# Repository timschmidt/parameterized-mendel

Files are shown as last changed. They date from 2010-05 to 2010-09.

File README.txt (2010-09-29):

Parameterized Mendel
====================

http://reprap.org/wiki/Parameterized_Mendel

This repository contains CAD files for the RepRap Mendel model 3D printer.

The v1.0 directory is intended to house a version of the Mendel which closely resembles the one initially released at reprap.org. Bugfixes and minor improvements will be incorporated, but always with an eye toward backwards compatibility.

The v1.1 directory is intended to house current development on the Mendel CAD files, including but not limited to porting to the MCAD library, radical improvements, and integration with the Huxley CAD files.

The experimental directory is a place for ideas to be developed, awaiting integration into either v1.0 or v1.1.

The utilities directory houses various programs which developers and end users may find useful when working with the CAD files.

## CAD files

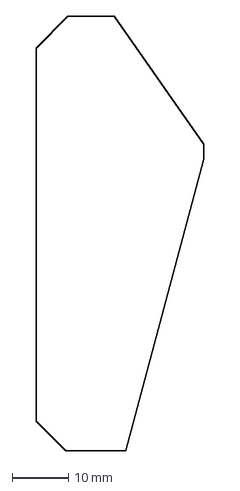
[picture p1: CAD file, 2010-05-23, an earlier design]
v1.0/y-idler-bracket-outline.dxf
29.7 x 76.9 mm

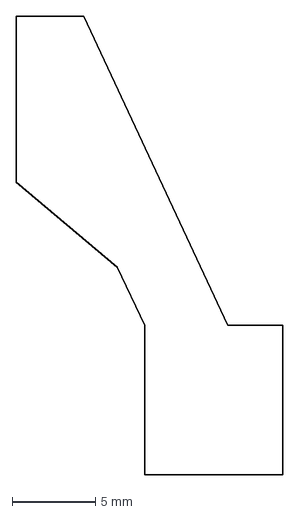
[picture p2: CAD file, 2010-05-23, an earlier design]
v1.0/x-360-z-bearing-plate-bottom-outline.dxf
16.0 x 27.6 mm

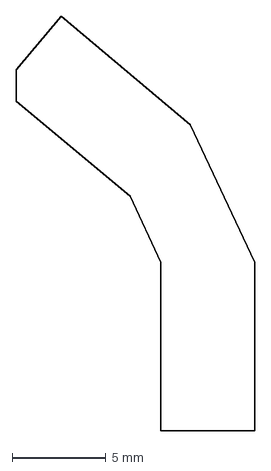
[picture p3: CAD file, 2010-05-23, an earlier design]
v1.0/x-360-z-bearing-plate-top-outline.dxf
12.7 x 22.1 mm

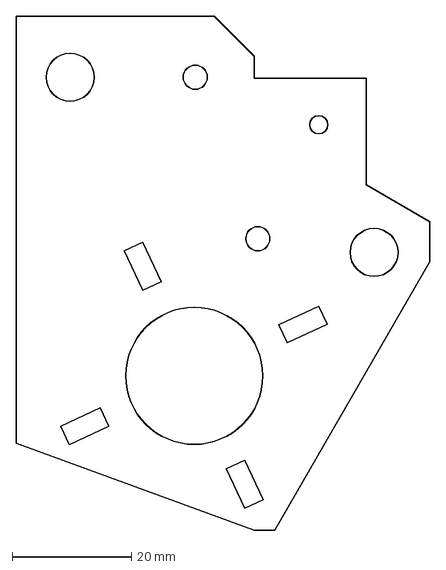
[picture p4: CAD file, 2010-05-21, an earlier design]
v1.0/y-motor-bracket.dxf
69.4 x 86.2 mm

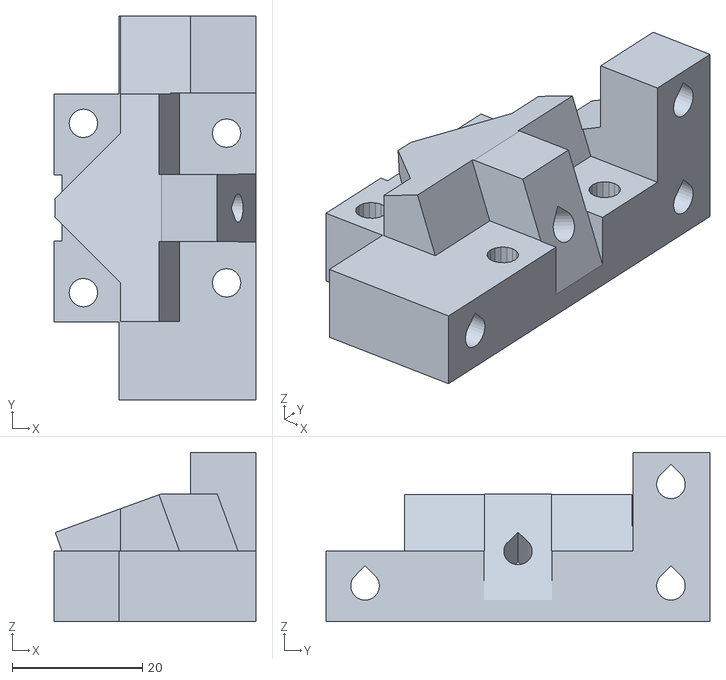
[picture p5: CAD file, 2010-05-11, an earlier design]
v1.0/y-bearing-360-outer-left_1off.stl
31.0 x 59.0 x 26.0

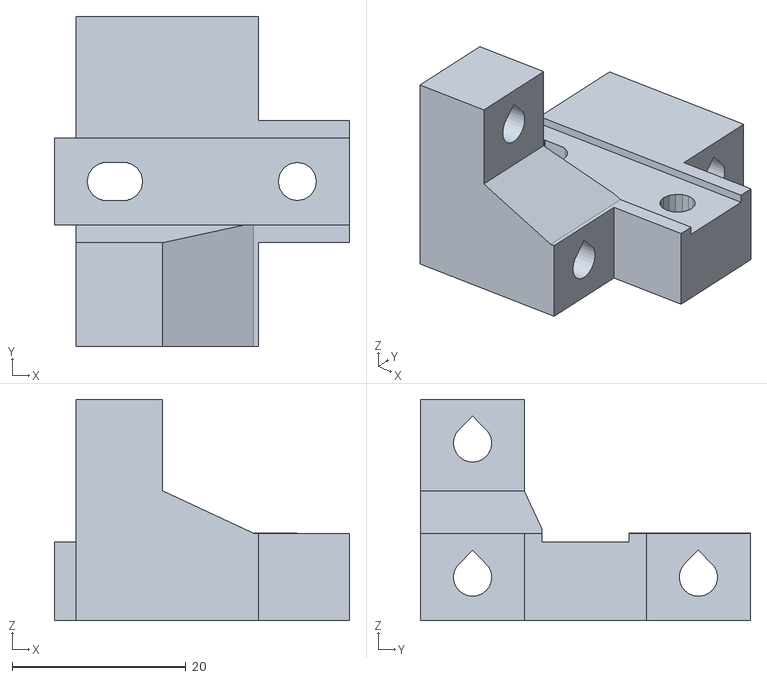
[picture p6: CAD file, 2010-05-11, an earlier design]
v1.0/y-bearing-180-outer-left_1off.stl
34.0 x 38.0 x 25.5

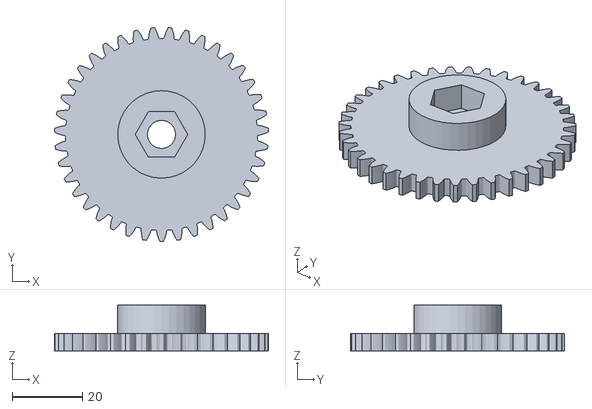
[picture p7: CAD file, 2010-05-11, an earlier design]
v1.0/39t17p.stl
61.1 x 61.1 x 13.0

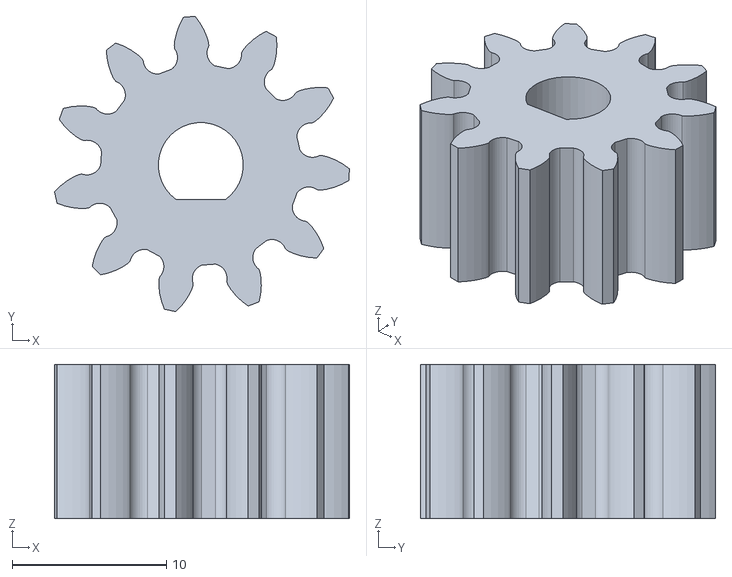
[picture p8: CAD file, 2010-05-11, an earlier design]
v1.0/11t17p.stl
19.1 x 19.1 x 10.0

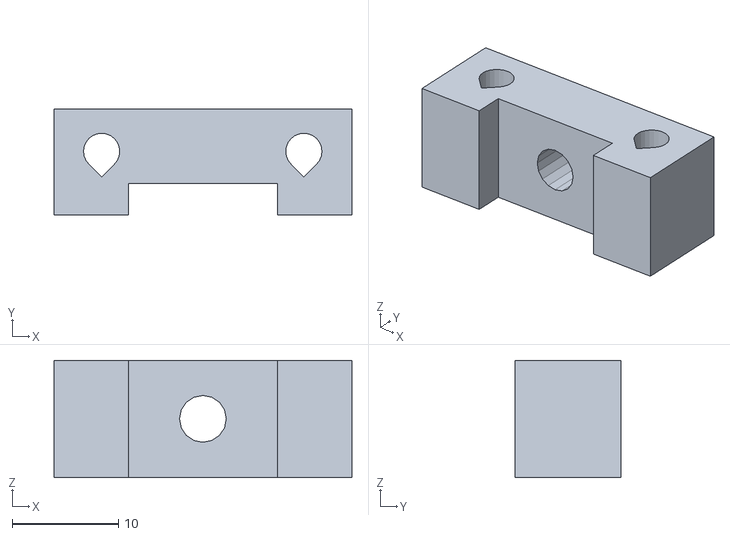
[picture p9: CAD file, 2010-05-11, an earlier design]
v1.0/z-opto-bracket_1off.stl
28.0 x 9.99 x 11.0

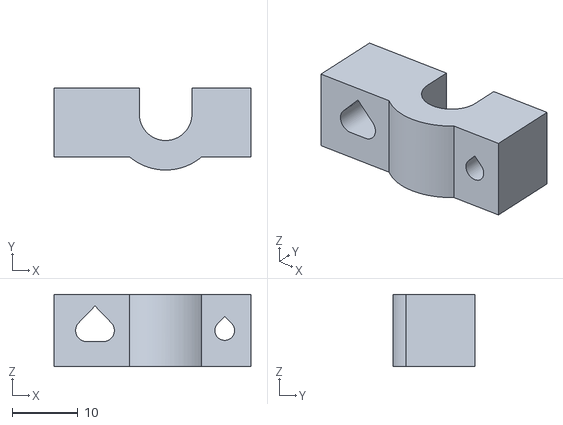
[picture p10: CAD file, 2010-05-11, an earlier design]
v1.0/x-bar-clamp-m3_6off.stl
30.0 x 12.5 x 11.0

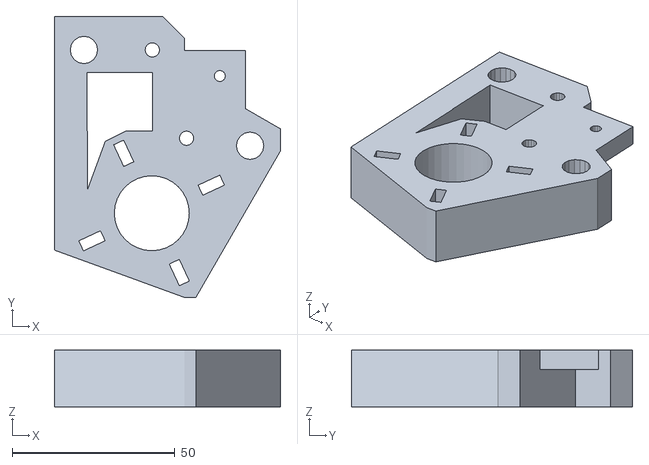
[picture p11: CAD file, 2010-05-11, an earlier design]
v1.0/y-motor-bracket_1off.stl
69.4 x 86.2 x 17.5

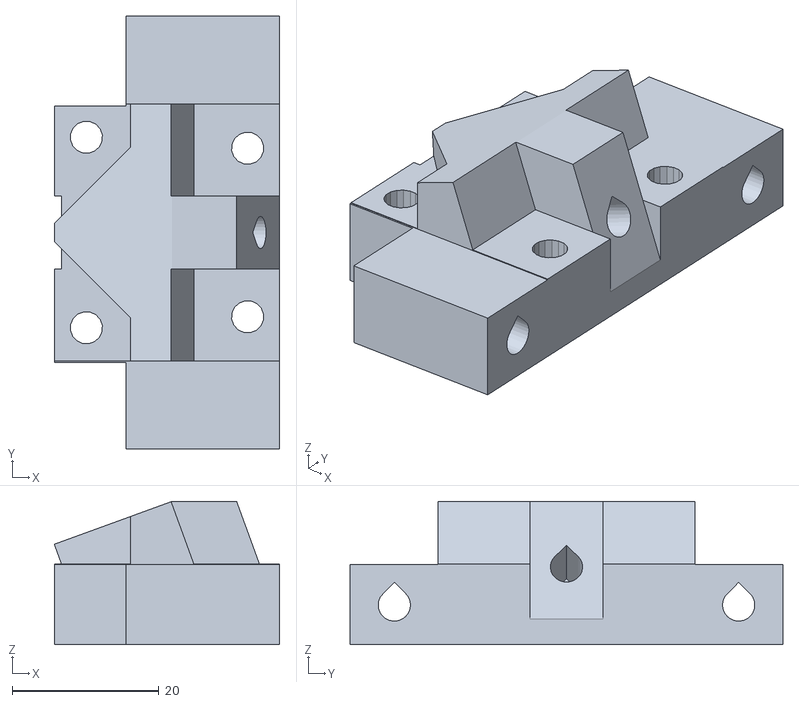
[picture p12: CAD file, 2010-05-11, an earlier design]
v1.0/y-bearing-360-inner_2off.stl
30.7 x 59.1 x 19.5

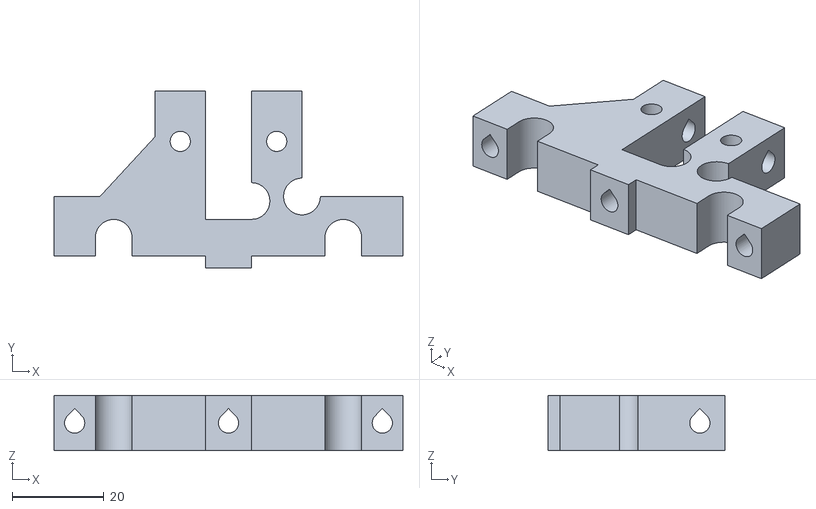
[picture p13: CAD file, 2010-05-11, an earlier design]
v1.0/x-180-z-bearing-plate_2off.stl
76.0 x 38.6 x 12.0

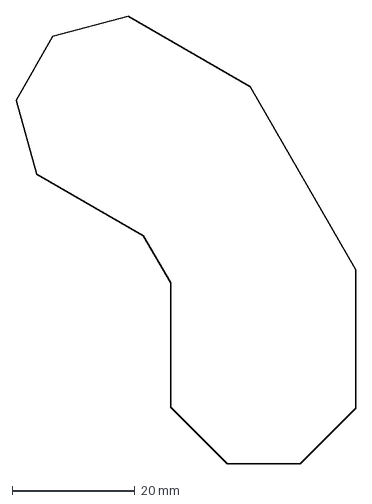
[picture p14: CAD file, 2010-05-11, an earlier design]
v1.0/frame-vertex.dxf
55.4 x 72.9 mm

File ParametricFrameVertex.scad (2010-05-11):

// Parametric Frame Vertex by Tonokip
// 2009.02.08
// Vertex Body derived from: frame-vertex_6off.aoi::body - edges
// http://reprap.svn.sourceforge.net/viewvc/reprap/trunk/mendel/mechanics/solid-models/cartesian-robot-m4/printed-parts/
// Fixed body geometry flaw per http://dev.forums.reprap.org/read.php?1,30132,30398
// License GNU GPL v2 or newer.

M3=4.3; 
M8=9.6;
vertex_height=20;
with_foot=1;		// Comment out for no foot.

FN=80;

translate ([0,0,vertex_height/2])difference() 
{
	union () {
		dxf_linear_extrude(file = "vertex-body-fixed-qcad.dxf",height=vertex_height,center=true);
		//import_stl("vertex-body-fixed.stl");
		if (with_foot==1) {
			translate([40,-15,0]) vertex_foot();
		}
	}

	translate([11.013,59.912]) zhole(M8); 
	translate([35.013,39.999,0]) zhole(M8); 
	translate([40.274,9.249,0]) zhole(M8); 
	translate([40.217,30.992]) zhole(M3); 
	translate([29.829,48.986]) zhole(M3); 
	translate([0,21,0]) 
		xteardrop(M8,200);
	translate([13.687,41.010,0]) rotate(a=60,v=[0,0,1])
		xteardrop(M8,200);
}


module zhole(diameter) cylinder(h=100,r=(diameter/2),center=true,$fn=FN); 

module xteardrop(diameter,length) rotate(a=-90,v=[0,1,0]) rotate(a=-90,v=[0,0,1]) zteardrop(diameter,length);

module yteardrop(diameter,length) rotate(a=90,v=[1,0,0]) zteardrop(diameter,length);

module zteardrop(diameter,height)
{
	rotate(a=45, v=[0,0,1]) union()
	{
		translate([0,0,-height/2]) cube(size=[diameter/2,diameter/2,height],center=false);
		cylinder(r=diameter/2, h = height,center=true,$fn=FN);
	}
}

module vertex_foot() {
	difference () {
		union () {
			cube([18,4,vertex_height],center=true);
			translate ([-5,8,0]) cube([5,18,vertex_height],center=true);
			translate ([5,9,0]) cube([5,18,vertex_height],center=true);
		}
		translate ([0,8,0]) xteardrop(7,200);
	}
}

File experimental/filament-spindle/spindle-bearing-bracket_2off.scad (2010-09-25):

/*
 *  Mendel Filament Spindle Bearing Bracket 2off
 *  by Tony Buser <tbuser@gmail.com>
 *
 *  This program is free software; you can redistribute it and/or modify
 *  it under the terms of the GNU General Public License as published by
 *  the Free Software Foundation; either version 3 of the License, or
 *  (at your option) any later version.
 *
 *  This program is distributed in the hope that it will be useful,
 *  but WITHOUT ANY WARRANTY; without even the implied warranty of
 *  MERCHANTABILITY or FITNESS FOR A PARTICULAR PURPOSE.  See the
 *  GNU General Public License for more details.
 *
 *  You should have received a copy of the GNU General Public License
 *  along with this program; if not, write to the Free Software
 *  Foundation, Inc., 59 Temple Place, Suite 330, Boston, MA  02111-1307  USA
*/

include <../mendel.inc>
include <../mendel.conf>

include <spindle.scad>

bearing_bracket_width = 22;
bearing_bracket_length = 21;
bearing_bracket_height = 33;

module bearing_bracket() {
	difference () {

		// TODO: chamfer?
		box(bearing_bracket_width, bearing_bracket_length, bearing_bracket_height);

		// shaft
		translate([0, bearing_bracket_length/2-rod_diameter+1, bearing_bracket_height/2-rod_diameter+1]) {
			rotate([-90, 0, -90]) {
				spindle_hole_horiz(bearing_bracket_width+2);
			}
		}

		// front nut
		translate([0, -bearing_bracket_length/2+3-1, bearing_bracket_height/2-rod_diameter+1]) {
			// top side cutout
			translate([0, 0, rod_diameter/2]) box(rod_diameter, rod_diameter-1, rod_diameter);

			rotate([0, -90, 90]) {
				spindle_hole_vert(rod_diameter+2);
			}
			rotate([90, 0, 0]) {
				spindle_nut_cavity(rod_diameter-1);
			}
		}

	}
}

translate([0, 0, bearing_bracket_length/2]) {
	rotate([-90]) bearing_bracket();
}

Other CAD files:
v1.0/y-bearing-180-outer-right_1off.stl
v1.0/y-bearing-180-inner_2off.stl
v1.0/y-bearing-360-outer-right_1off.stl
v1.0/x-axis-side-plate-nut-jig_2off.stl
experimental/filament-spindle/spindle-corner-bracket_8off.scad
experimental/filament-spindle/spindle-hub_1off.scad
experimental/bfb-and-dualhead/mendel_x_carriage_lower_bfb.scad
experimental/bfb-and-dualhead/mendel_x_carriage_lower_bfb_2head.scad
experimental/bfb-and-dualhead/mendel_x_carriage_upper_bfb_2head.scad
experimental/filament-spindle/spindle-spool-hub_1off.scad
experimental/filament-spindle/spindle-spool-spoke_4off.scad
experimental/filament-spindle/spindle-support-bearing-bracket_4off.scad
experimental/filament-spindle/spindle-tube-fitting.scad
experimental/filament-spindle/spindle-tube-holder_1off.scad
experimental/filament-spindle/spindle.scad
experimental/gears_spur.scad
experimental/huxley/Huxley.scad
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

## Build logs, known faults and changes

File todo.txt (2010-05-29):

Todo:

-- Short Term Goals --
 - replace all STLs with OpenSCAD files

-- Medium Term Goals --
 - improve parameterization
  - move all defined constants into mendel.conf
  - consolidate modules in mendel.inc
  - re-use constants and modules wherever possible
  - create commented pre-defined configurations of the mendel in mendel.conf for easy selection of a few major variants

-- Long Term Goals --
 - improve servicability
  - re-design parts to allow any individual part to be removed without requiring significant disassembly
  - modify parts for easy tool access after installation

-- Individual Items --
 - fix vik's fudging of various hole diameters
 - unify z leadscrew base, z motor bracket, and z tensioner bracket files - optionally render as individual or combined parts
 - parameterize foot height on frame vertex, and make middle three holes optional
 - merge x carriage upper and lower with modified bfb versions
 - thin the X vert drive side plate 180 a bit, to reduce X axis guide rod bending
 - add nut trap void to x vert side plate 180, eliminate nut trap jig part.
 - de-couple the Z drive trapped nut a bit, to dampen drive rod wobble

-- Additions from fen for mini-mendel --
z axis rod clamp is not the same spacing as other 6mm clamp arch thingies
clamp arch thingies should accept 20mm m3 shcs
clamp arch thingies are too small for 6mm rods
clamp arch thingies should work with 20mm m3's, and have hexagon nut holders
90 degree thingies should only need 1 clamp screw each
y front clamp thingy screws interfere with nema 17 motor
enlarge 22mm holes in motor connector interfaces to accomodate larger pulley hubs + set screws sticking out

reduce number of 30mm m3's to <50 qty
eliminate 12mm m3's
z axis 180 should be 1 piece.. shouldnt need washers to offset the bearings
move z 180 side leadscrew closer to smooth z rod, to increase x travel
space for washer on z 360 piece. reengineer z 360 assy to not need threaded rod
add holes for nema17 on x y z
z nut traps only need 4 screws, two on the outside, and front and back of the screw
get rid of nut traps on y chassis
fix misaligned counterbore on x carriage
get rid of counterbores on x carriage, switch to hexagons
x-carriage hexagon should be symmetrical (two less holes? what are they for?)
x carriage triangular lumps may interfere with bearing next to it
x carriage triangular lumps need nut bearing surface on opposite side
x carriage needs a little more stiffness (thickness at thinnest part)
x carriage diagonal 30mm m3's interfere with vertical 20mm's (barely)
x carriage should be symmetrical distance from rods or belt will rub on backside
x carriage only needs one vertical 360 bearing and should have outer diagonals on ends (wider wheelbase = more rigidity against racking forces)
speaking of racking forces, belt clamp should be more central (offset motor, huge redesign of x axis)
belt clamp should have same spacing as arch thingies
y 360 sliders are too wide for 30mm m3+two nuts + lock washer (barely) (+two washers would be nice)
only need 2 y 180's, not 4
true kinematic design would use less bearings
lower y axis somehow, it's too much clearance between bottom of y and bottom of machine, i.e. switch z tension rods+frame rods
purge plate gets really close to y motor bracket
wtf is purge plate for??
need more 623 bearings in BOM
should have adjustable (spring?) tension idlers for x and y belts
y idler washers overlap < 1mm
z has way too many idler pulleys (should have like one tensioner and that's it)
z leadscrew blocks are too tall for 30mm to comfortably fit idlers
use timing pulley for y idler instead of smooth?
nophead pulley needs counterbore for m3 shcs head, or switch to clamp configuration instead of set screw
y motor bracket doesn't clear nophead pulley base
brackets shouldn't have full circle holes, should be slots for easy removal, or clamps
something's fucked up with the y axis belt - the top half of the loop makes a triangle instead of a line, this causes tension changes (oops my frog was on upside down, this could be clearer in the docs)
y (and x?) belt clamp don't work with m12's (maybe this is ok)
you really do need to use lock nuts on the frame pieces <- hmm. maybe not
#12 SAE lock washers don't fit on M6 threaded rod, FYI

some measurements:
x travel: 126mm
y travel: 154mm <- more like 145mm because of some belt tension weirdness at the motor end
10 washers on each idler pulley; could be reduced with 20mm's and jamb nuts instead

x idler pulley to bar: 8mm
x carriage clamp face to bar: 17mm
x carriage opposite face to bar: 20mm

x blunt plate:
 width: 54mm
 height: 24mm
 thickness: 4mm
 horizontal hole spacing: 46.5mm
 vertical hole spacing: 14mm

hardware used: (first count)
m3x30: 39
m3x20: 70
m3x12: 18? 24?
m6 nut: 88
m6 washer: 74?
m3 fender washer:
m3 washer:
m3 lock washer:

existing stepper hookup:
sync sync enable max min dir step gnd
BW B OW O NW G GW N

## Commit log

2010-05-12 updated mendel_x_carriage_lower to vik's latest version
    [mendel_x_carriage_lower.scad]
2010-05-12 updated mendel_x_carriage_upper to vik's latest version
    [mendel_x_carriage_lower.stl, mendel_x_carriage_upper.scad]
2010-05-12 updated mendel_x_motor_bracket to vik's latest version
    [mendel_x_motor_bracket.scad]
2010-05-12 updated mendel_z_leadscrew_base to vik's latest version
    [mendel_z_leadscrew_base.scad]
2010-05-12 replace mendel_z_motor_bracket with vik's openscad version
    [mendel_z_motor_bracket.scad, z-motor-bracket_1off.stl]
2010-05-12 replace mendel_y_bar_clamp with vik's openscad version
    [y-bar-clamp_10off-REMAKE.scad, y-bar-clamp_10off.stl]
2010-05-12 added vik's PCB holder
    [mendel_holder_module.scad]
2010-05-12 replace mendel_x_belt_clamp with vik's openscad version
    [mendel_x_belt_clamp.scad, x-carriage-belt-clamp_2off.stl]
2010-05-12 replace mendel_y_belt_clamp with vik's openscad version
    [mendel_y_belt_clamp.scad, y-belt-clamp_2off.stl]
2010-05-12 added optional parts for vik's kiwi mendel fork
    [beaded-belt_gear.scad, mendel_dc_extruder.scad, mendel_extruder.scad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]
2010-05-12 replace pulley with GilesBathgate's openscad version
    [pulley.scad, pulley.stl]
2010-05-12 promoted the pcb clamp
    [pcb_clamp.scad]
2010-05-13 vik's pcb clamp and mendel holder module supercede this part
    [circuit-board-bracket-m3_4off.stl]
2010-05-14 added bfb and dualhead forks for integration
    [mendel_x_carriage_lower_bfb.scad, mendel_x_carriage_lower_bfb_2head.scad, mendel_x_carriage_upper_bfb.scad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]
2010-05-14 spruced up single/dual extruder selection in mendel_misc.inc
2010-05-14 integrated mainline and bfb mendel_x_carriage_upper
    [mendel_x_carriage_upper.scad, mendel_x_carriage_upper_bfb.scad]
2010-05-16 separated mendel.inc into mendel.inc (for modules) and mendel.conf (for configurable parameters)
    [mendel_holder_module.scad, mendel_x_belt_clamp.scad, mendel_x_carriage_lower.scad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]
2010-05-16 replace zPulley_2ofMBC with improved OpenSCAD version
    [zPulley_2ofMBC.STL, z_pulley.scad]
2010-05-16 fixed z height on z_pulley
    [z_pulley.scad]
2010-05-17 added len's x-motor-bracket-spacer
    [x-motor-bracket-spacer_2off.scad]
2010-05-19 added utility directory, and filled it with an OpenSCAD script for generating NEMA 23 / 17 motors
    [utl.NEMA.scad]
2010-05-19 normalized file names
    [frame-vertex.dxf, frame-vertex.scad, geared-extruder.scad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]
2010-05-19 renamed Hub to spool-holder
    [spool-holder.scad]
2010-05-19 normalized name
    [x-motor-bracket-spacer.scad]
2010-05-19 added some notes to mendel.scad
    [mendel.scad]
2010-05-19 replaced M8_Extruder_Idler_Block with OpenSCAD version
    [M8_Extruder_Idler_Block_2.stl, extruder-idler-bracket.scad, y-idler-bracket.scad]
2010-05-19 added gears_spur.scad utility file - will modify to re-create gears for wade's extruder
    [gears_spur.scad]
2010-05-20 checked an item off the todo list
    [beaded-belt_gear.scad]
2010-05-20 replaced circuit-board-spacer with OpenSCAD version
    [circuit-board-spacer-m4_2off.stl, circuit-board-spacer.scad]
2010-05-20 replaced x-vert-drive-nut-trap with OpenSCAD version
    [x-vert-drive-nut-trap.scad, x-vert-drive-nut-trap_4off.stl]
2010-05-20 fixed orientation for printing on extruder-idler-bracket
    [extruder-idler-bracket.scad]
2010-05-20 fixed orientation for printing
    [x-vert-drive-nut-trap.scad]
2010-05-20 replace x-vert-drive-side-plate-180 with openscad version
    [x-vert-drive-side-plate-180-end_2off.stl, x-vert-drive-side-plate-180.scad, x-vert-drive-side-plate-180.stl]
2010-05-20 remove accidental stl
    [x-vert-drive-side-plate-180.stl]
2010-05-20 replace x-vert-drive-side-plate-360 with OpenSCAD version
    [x-vert-drive-side-plate-360-end_2off.stl, x-vert-drive-side-plate-360.scad]
2010-05-21 replaced z-tensioner with OpenSCAD version
    [z-tensioner.scad, z-tensioner_1off.stl]
2010-05-21 slight modification to z-tensioner
    [z-tensioner.scad]
2010-05-21 replaced z-leadscrew-base-bar-clamp with OpenSCAD version
    [z-leadscrew-base-bar-clamp.scad, z-leadscrew-base-bar-clamp_2off.stl]
2010-05-21 fixed print orientation of z-leadscrew-base-bar-clamp
    [z-leadscrew-base-bar-clamp.scad]
2010-05-21 replace z-bar-top-clamp with OpenSCAD version
    [z-bar-top-clamp.scad, z-bar-top-clamp_4off.stl]
2010-05-21 added Tonok's y-motor-bracket.dxf under GPL v2 or later
    [y-motor-bracket.dxf]
2010-05-21 added fenn's two timing pulley scripts to the utility folder, will check to make sure they have sane defaults, then replace my pulley with one of them
    [timingPulley-v2.scad, timingPulley.scad]
2010-05-21 removed timingPulley.scad, as it was nearly identical to timingPulley-v2.scad
    [timingPulley.scad]
2010-05-21 moved teardrop module from timingPulley to mendel.inc
    [timingPulley-v2.scad]
2010-05-21 promoted timing-pulley
    [timing-pulley.scad]
2010-05-23 python script that will generate all the stl files
    need to automate the whole build process
2010-05-23 replaced x-360-z-bearing-plate with OpenSCAD version by Tonok
    [x-360-z-bearing-plate-bottom-outline.dxf, x-360-z-bearing-plate-top-outline.dxf, x-360-z-bearing-plate.scad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]
2010-05-23 replaced y-idler-bracket with OpenSCAD version by Tonok
    [y-idler-bracket-outline.dxf, y-idler-bracket.scad]
2010-05-23 removed y-idler-bracket stl
    [y-idler-bracket_1off.stl]
2010-05-24 updated z-bar-top-clamp with changes by Tonok
    [z-bar-top-clamp.scad]
2010-05-24 vik improved extruder-idler-bracker
    [extruder-idler-bracket.scad]
2010-05-24 added vik's DC extruder
    [mendel_dc_extruder2.scad]
2010-05-25 Start of de-scalaring and parameter work
    Need to extract common modules and values.
    -- Create a structured folder set for scad-mendel
2010-05-25 added nicholasclewis' combined z leadscrew base and z motor mount
    [mendel_z_leadscrew_baseWithMotor.scad]
2010-05-25 fixed up the combined z parts a bit
    [mendel_z_leadscrew_baseWithMotor.scad]
2010-05-25 removed a highlight from the extruder-idler-bracket
    [extruder-idler-bracket.scad]
2010-05-25 normalize names of some of the new files
    [dc-extruder.scad, z-axis-combined-leadscrew-base.scad]
2010-05-26 Python tokenizer for cleaning up
    Currently find duplicate module definitions
    Need to work on variable name and scalar extraction
2010-05-28 removed x-end-bracket
    [x-end-bracket_2off.stl]
2010-05-28 replaced x-end-bracket with OpenSCAD version
    [x-end-bracket.scad]
2010-06-13 replaced x-bar-clamp-m4 with OpenSCAD version
    [x-bar-clamp-m4.scad, x-bar-clamp-m4_4off.stl]
2010-06-14 variant of XLR-bracket that supports both XLR and Coax power connectors
    [power-bracket_1off.scad]
2010-06-14 normalized names
    [power_bracket.scad]
2010-06-15 replaced x-360-z-bearing-plate-mirror with an addition to x-360-z-bearing-plate
    [x-360-z-bearing-plate-mirror_2off.stl, x-360-z-bearing-plate.scad]
2010-08-06 changed includes to new OpenSCAD syntax
    [power-bracket_1off.scad]
2010-08-06 added my filament-spindle design
    [spindle-bearing-bracket_2off.scad, spindle-corner-bracket_8off.scad, spindle-hub_1off.scad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]
2010-09-24 initial commit of Whosawhatsis' parametric Huxley work
    [Huxley.scad, carriage.scad, carriagetry.scad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]
2010-09-29 reorganized files to promote work on both a stable and development version of Mendel.
    [11t17p.stl, 39t17p.stl, Huxley.scad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]
2010-09-29 Revert "reorganized files to promote work on both a stable and development version of Mendel."
    This reverts commit 1631fcb9ff86a6f46f141d4160faa34e12c048aa.
    [11t17p.stl, 39t17p.stl, Huxley.scad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]
2010-09-29 reorganized files to promote development on both a stable and development version of the Mendel CAD files
    [11t17p.stl, 39t17p.stl, Huxley.scad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]
